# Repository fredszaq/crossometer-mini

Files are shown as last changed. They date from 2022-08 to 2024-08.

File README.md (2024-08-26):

# crossometer-mini

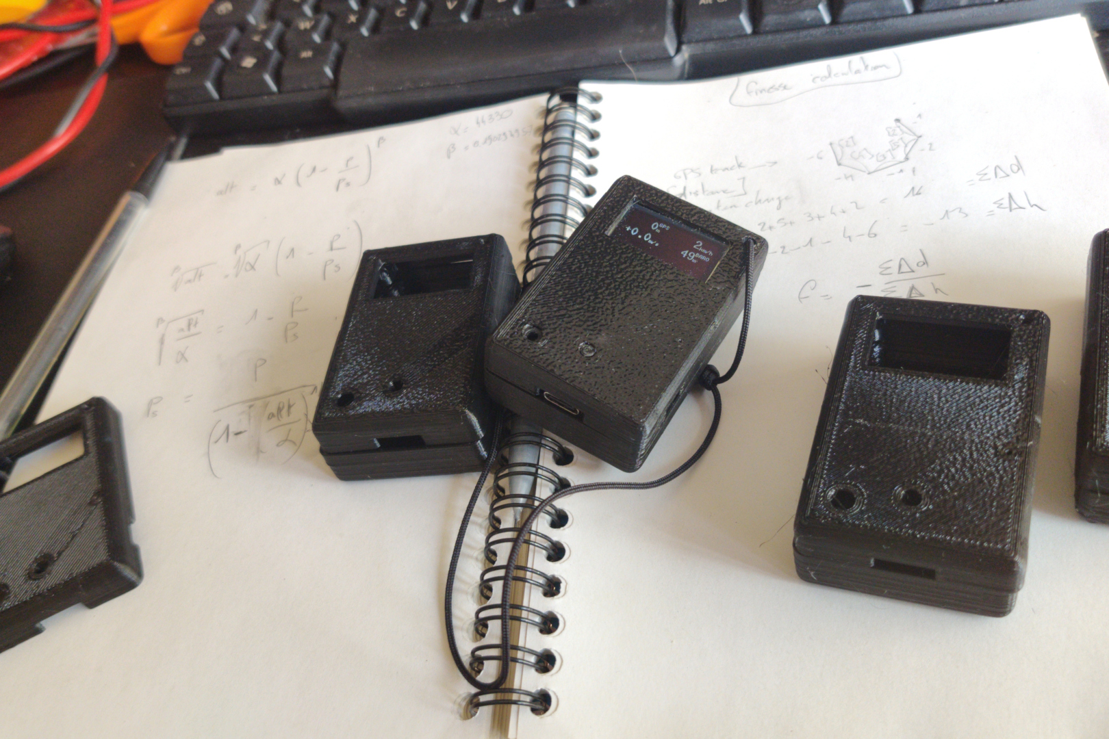
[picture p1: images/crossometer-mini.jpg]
crossometer-mini


This repo contains the design files for the crossometer-mini device, an open hardware GPS/altimeter/variometer using the [crossometer-firmware](https://github.com/fredszaq/crossometer-firmware).

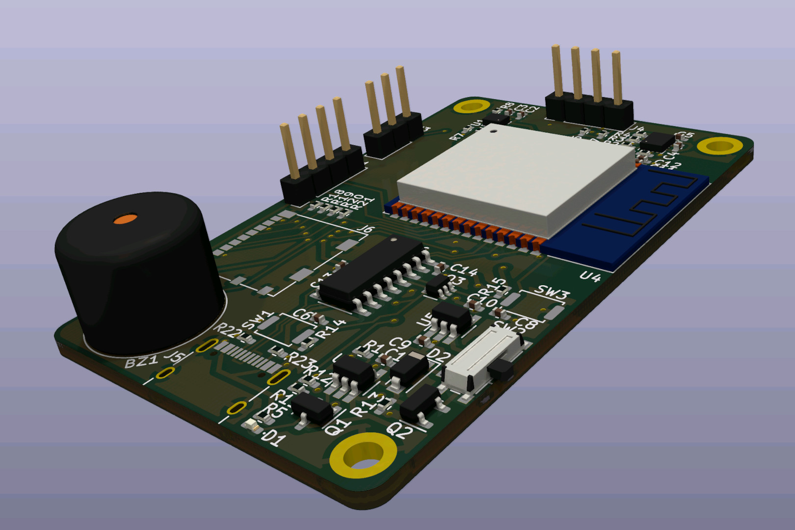
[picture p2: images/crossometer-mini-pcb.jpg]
crossometer-mini pcb


Provided are the Kicad files for the PCB and the Freecad files for the enclosure and clip.

Taking a look at open [issues](https://github.com/fredszaq/crossometer-mini/issues) may be a good idea if you intent do build a crossometer-mini for yourself.

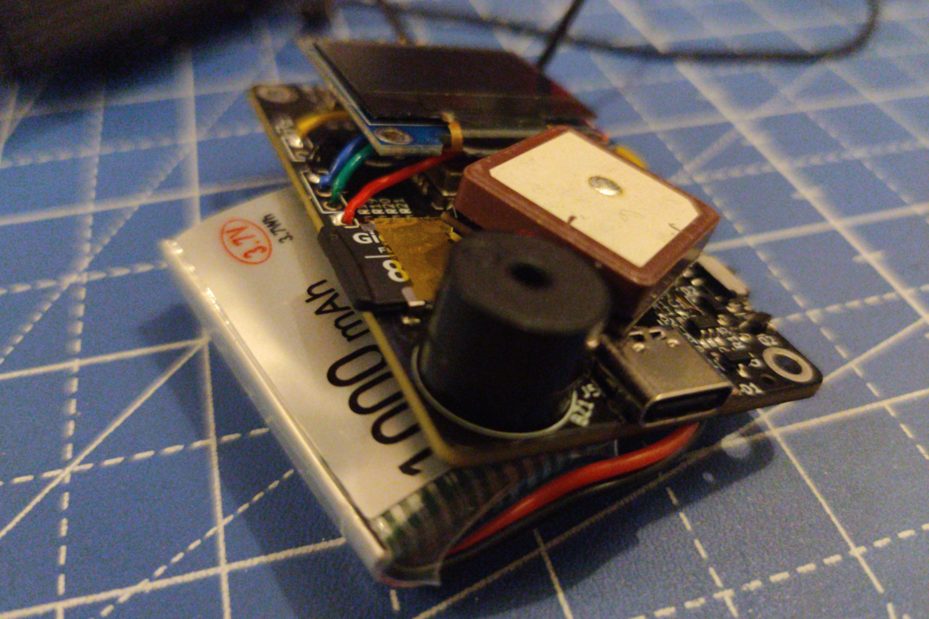
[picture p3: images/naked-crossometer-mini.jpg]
crossometer-mini without 3 case


Have a look at the [releases](https://github.com/fredszaq/crossometer-mini/releases) page to get gerber files and STLs.

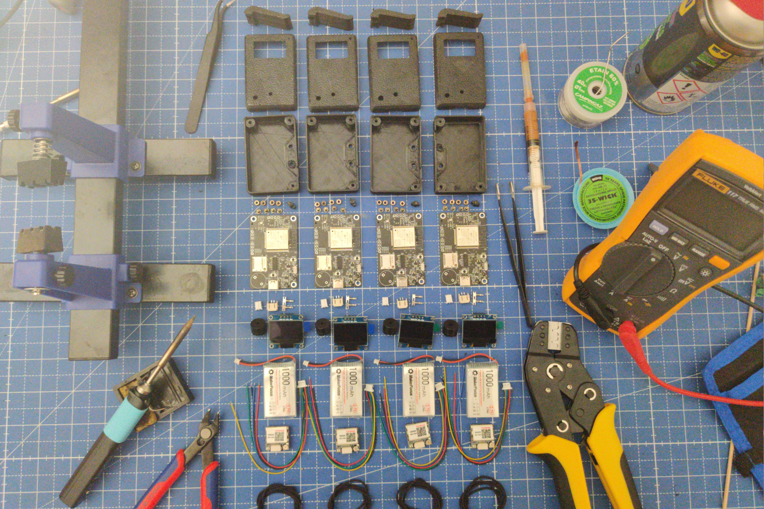
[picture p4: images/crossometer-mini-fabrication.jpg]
4 crossometer-mini before assembly


crossometer-mini is licenced under the CERN Open Hardware Licence Version 2 - Strongly Reciprocal

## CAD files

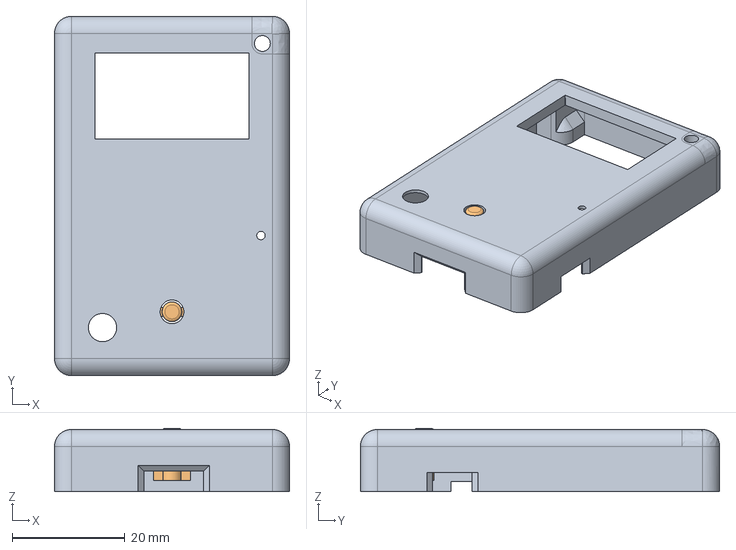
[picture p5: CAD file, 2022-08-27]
crossometer-mini.FCStd
41.6 x 63.6 x 11.2 mm
top
button

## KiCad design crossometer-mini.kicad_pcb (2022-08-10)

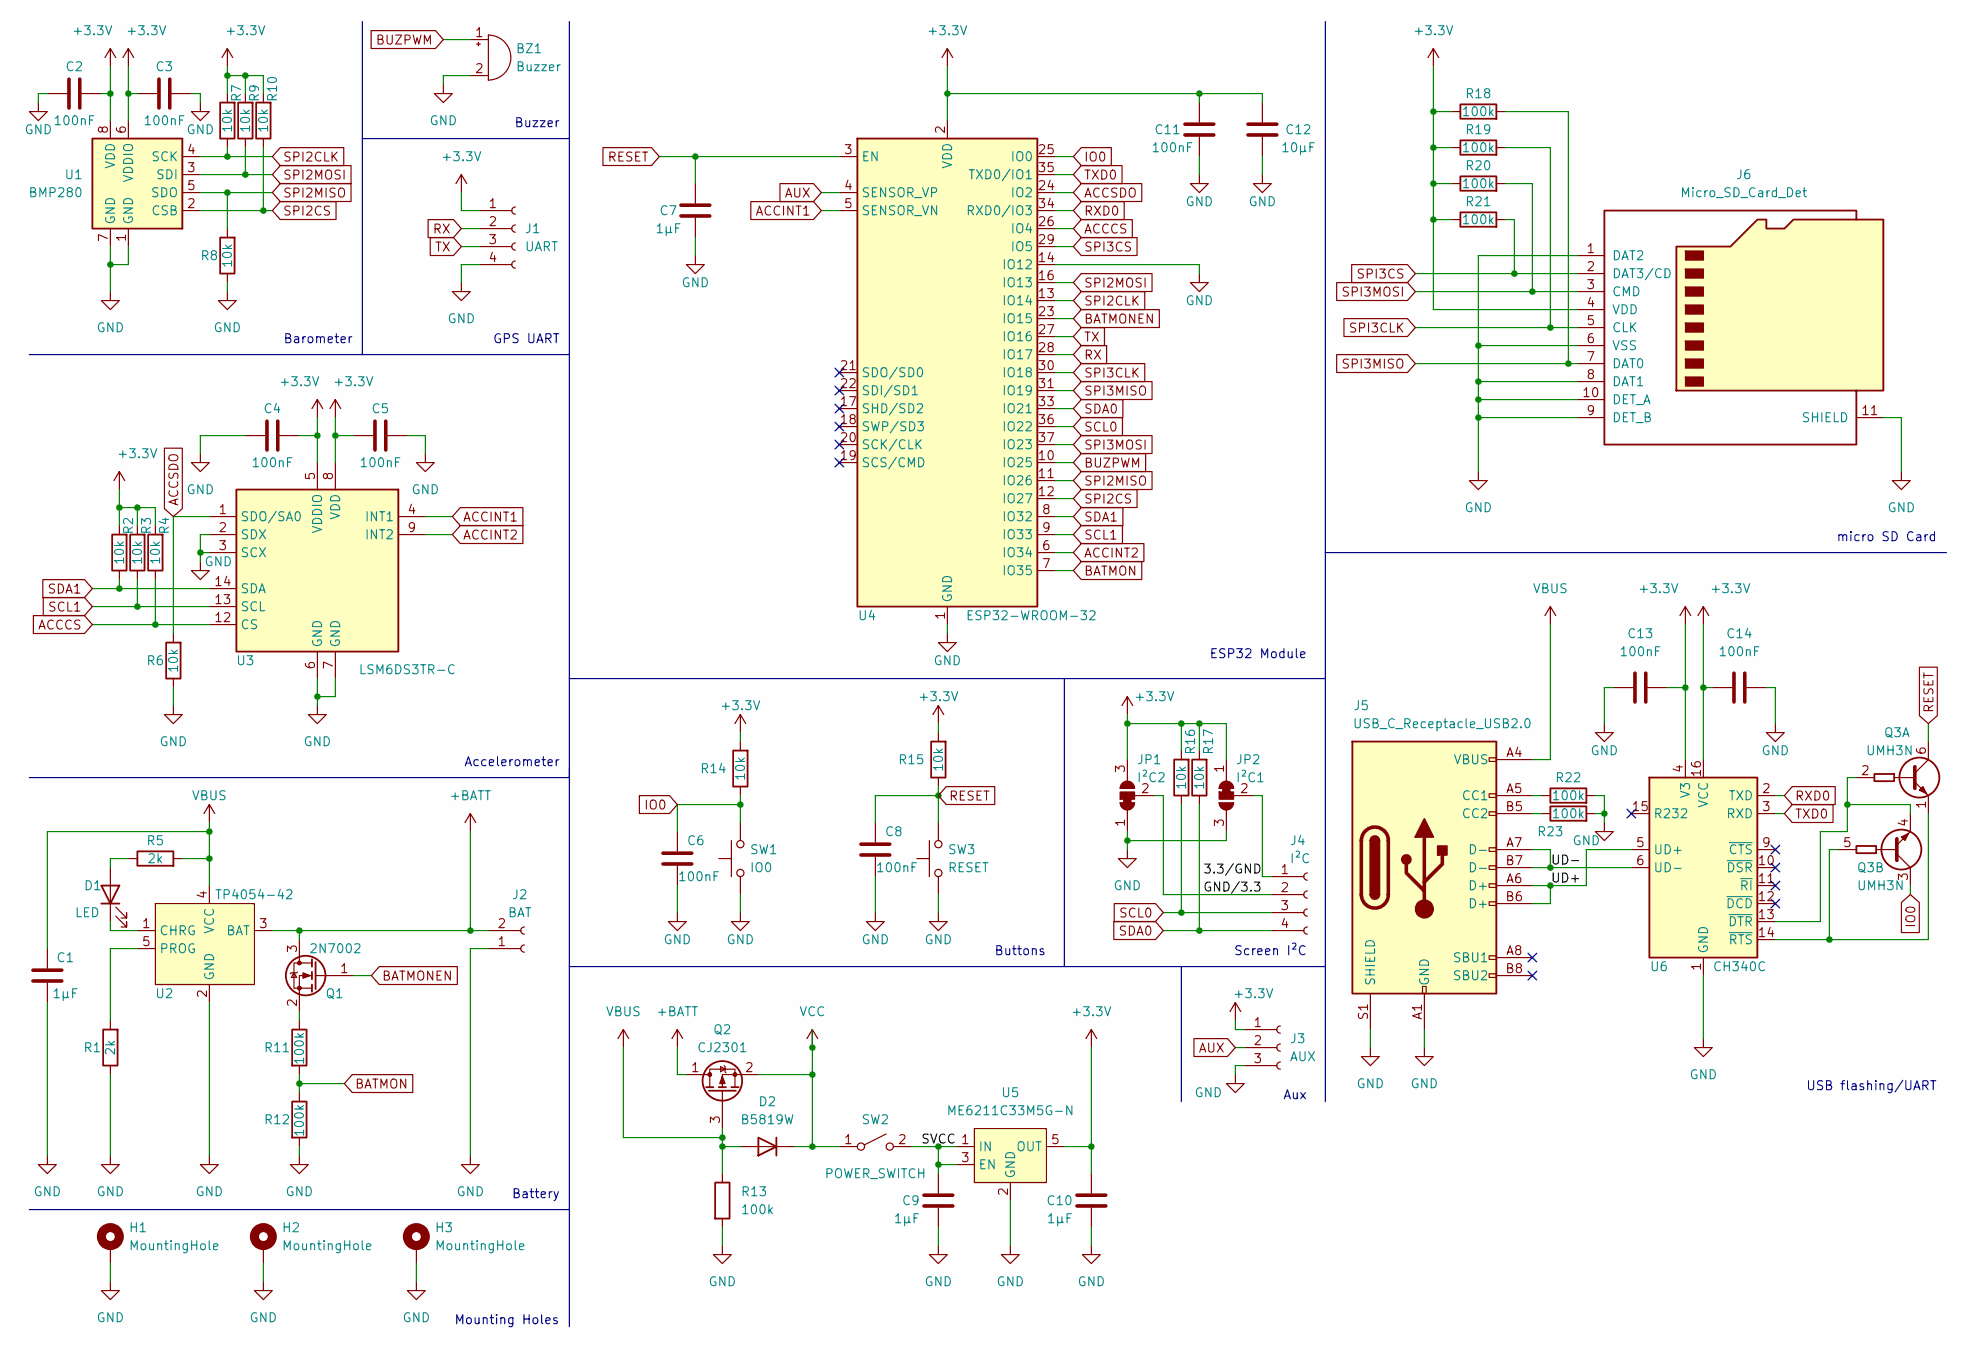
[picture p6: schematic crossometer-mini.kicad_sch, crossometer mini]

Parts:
BZ1: Buzzer; Buzzer_12x9.5RM7.6
C1, C7, C9, C10: 1µF; C_0402_1005Metric_Pad0.74x0.62mm_HandSolder; LCSC C52923
C2, C3, C4, C5, C6, C8, C11, C13, C14: 100nF; C_0402_1005Metric_Pad0.74x0.62mm_HandSolder; LCSC C1525
C12: 10µF; C_0402_1005Metric_Pad0.74x0.62mm_HandSolder; LCSC C15525
D1: LED; LED_0402_1005Metric_Pad0.77x0.64mm_HandSolder; LCSC C965790
D2: B5819W; D_SOD-123; LCSC C8598
H1, H2, H3: MountingHole; MountingHole_2.7mm_M2.5_ISO7380_Pad
J1: UART; PinHeader_1x04_P2.54mm_Vertical
J2: BAT; JST_PH_S2B-PH-SM4-TB_1x02-1MP_P2.00mm_Horizontal
J3: AUX; PinHeader_1x03_P2.54mm_Vertical
J4: I²C; PinHeader_1x04_P2.54mm_Vertical
J5: USB_C_Receptacle_USB2.0; USB_C_Receptacle_XKB_U262-16XN-4BVC11; LCSC C319148
J6: Micro_SD_Card_Det; microSD_HC_Molex_104031-0811; LCSC C585350
JP1: I²C2; SolderJumper-3_P1.3mm_Bridged12_RoundedPad1.0x1.5mm_NumberL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
JP2: I²C1; SolderJumper-3_P1.3mm_Bridged12_RoundedPad1.0x1.5mm_NumberL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
Q1: 2N7002; SOT-23; LCSC C8545
Q2: CJ2301; SOT-23; LCSC C2910170
Q3: UMH3N; SOT-363_SC-70-6; LCSC C62892
R1, R5: 2k; R_0402_1005Metric_Pad0.72x0.64mm_HandSolder; LCSC C4109
R2, R3, R4, R6, R7, R8, R9, R10, R14, R15, R16, R17: 10k; R_0402_1005Metric_Pad0.72x0.64mm_HandSolder; LCSC C25744
R11, R12, R13, R18, R19, R20, R21, R22, R23: 100k; R_0402_1005Metric_Pad0.72x0.64mm_HandSolder; LCSC C25741
SW1: IO0; SW_Push_SPST_NO_Alps_SKRK; LCSC C115357
SW2: POWER_SWITCH; SW_SPDT_PCM12; LCSC C221841
SW3: RESET; SW_Push_SPST_NO_Alps_SKRK; LCSC C115357
U1: BMP280; Bosch_LGA-8_2x2.5mm_P0.65mm_ClockwisePinNumbering; LCSC C83291
U2: TP4054-42; SOT-23-5_HandSoldering; LCSC C32574
U3: LSM6DS3TR-C; Bosch_LGA-14_3x2.5mm_P0.5mm; LCSC C967633
U4: ESP32-WROOM-32; LCSC C82899
U5: ME6211C33M5G-N; SOT-23-5_HandSoldering; LCSC C82942
U6: CH340C; SOIC-16_3.9x9.9mm_P1.27mm; LCSC C84681

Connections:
+3V3: C2.1, C3.2, C4.1, C5.2, C10.1, C11.1, C12.1, C13.2, C14.1, J1.1, J3.1, J6.4 (VDD), JP1.3 (B), JP2.1 (A), R2.2, R3.2, R4.2, R7.2, R9.2, R10.2, R14.2, R15.2, R16.2, R17.2, R18.1, R19.1, R20.1, R21.1, U1.6 (VDDIO), U1.8 (VDD), U3.5 (VDDIO), U3.8 (VDD), U4.2 (VDD), U5.5 (OUT), U6.4 (V3), U6.16 (VCC)
+BATT: J2.2, Q1.3 (D), Q2.1 (D), U2.3 (BAT)
/3.3/GND: J4.1, JP2.2 (C)
/GND/3.3: J4.2, JP1.2 (C)
/SVCC: C9.1, SW2.2 (B), U5.1 (IN), U5.3 (EN)
/UD+: J5.A6 (D+), J5.B6 (D+), U6.5 (UD+)
/UD-: J5.A7 (D-), J5.B7 (D-), U6.6 (UD-)
ACCCS: R4.1, U3.12 (CS), U4.26 (IO4)
ACCINT1: U3.4 (INT1), U4.5 (SENSOR_VN)
ACCINT2: U3.9 (INT2), U4.6 (IO34)
ACCSDO: R6.2, U3.1 (SDO/SA0), U4.24 (IO2)
AUX: J3.2, U4.4 (SENSOR_VP)
BATMON: R11.2, R12.1, U4.7 (IO35)
BATMONEN: Q1.1 (G), U4.23 (IO15)
BUZPWM: BZ1.1 (-), U4.10 (IO25)
GND: BZ1.2 (+), C1.1, C2.2, C3.1, C4.2, C5.1, C6.2, C7.2, C8.2, C9.2, C10.2, C11.2, C12.2, C13.1, C14.2, H1.1, H2.1, H3.1, J1.4, J2.1, J3.3, J5.A1 (GND), J5.A12 (GND), J5.B1 (GND), J5.B12 (GND), J5.S1 (SHIELD), J6.1 (DAT2), J6.6 (VSS), J6.8 (DAT1), J6.9 (DET_B), J6.10 (DET_A), J6.11 (SHIELD), JP1.1 (A), JP2.3 (B), R1.1, R6.1, R8.1, R12.2, R13.2, R22.2, R23.2, SW1.1, SW3.1, U1.1 (GND), U1.7 (GND), U2.2 (GND), U3.2 (SDX), U3.3 (SCX), U3.6 (GND), U3.7 (GND), U4.1 (GND), U4.14 (IO12), U4.15 (GND), U4.38 (GND), U4.39 (GND), U5.2 (GND), U6.1 (GND)
IO0: C6.1, Q3.3 (C2), R14.1, SW1.2, U4.25 (IO0)
unnamed: D1.1 (K), U2.1 (CHRG)
unnamed: D1.2 (A), R5.1
unnamed: J5.A5 (CC1), R22.1
unnamed: J5.B5 (CC2), R23.1
unnamed: Q1.2 (S), R11.1
unnamed: Q3.1 (E1), Q3.5 (B2), U6.14 (~RTS)
unnamed: Q3.2 (B1), Q3.4 (E2), U6.13 (~DTR)
unnamed: R1.2, U2.5 (PROG)
RESET: C7.1, C8.1, Q3.6 (C1), R15.1, SW3.2, U4.3 (EN)
RX: J1.2, U4.28 (IO17)
RXD0: U4.34 (RXD0/IO3), U6.2 (TXD)
SCL0: J4.3, R16.1, U4.36 (IO22)
SCL1: R3.1, U3.13 (SCL), U4.9 (IO33)
SDA0: J4.4, R17.1, U4.33 (IO21)
SDA1: R2.1, U3.14 (SDA), U4.8 (IO32)
SPI2CLK: R7.1, U1.4 (SCK), U4.13 (IO14)
SPI2CS: R10.1, U1.2 (CSB), U4.12 (IO27)
SPI2MISO: R8.2, U1.5 (SDO), U4.11 (IO26)
SPI2MOSI: R9.1, U1.3 (SDI), U4.16 (IO13)
SPI3CLK: J6.5 (CLK), R19.2, U4.30 (IO18)
SPI3CS: J6.2 (DAT3/CD), R21.2, U4.29 (IO5)
SPI3MISO: J6.7 (DAT0), R18.2, U4.31 (IO19)
SPI3MOSI: J6.3 (CMD), R20.2, U4.37 (IO23)
TX: J1.3, U4.27 (IO16)
TXD0: U4.35 (TXD0/IO1), U6.3 (RXD)
VBUS: C1.2, D2.2 (A), J5.A4 (VBUS), J5.A9 (VBUS), J5.B4 (VBUS), J5.B9 (VBUS), Q2.3 (G), R5.2, R13.1, U2.4 (VCC)
VCC: D2.1 (K), Q2.2 (S), SW2.1 (A)

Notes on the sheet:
USB flashing/UART
micro SD Card
ESP32 Module
Accelerometer
Buttons
Buzzer
Mounting Holes
Battery
Screen I²C
GPS UART
Aux
Barometer

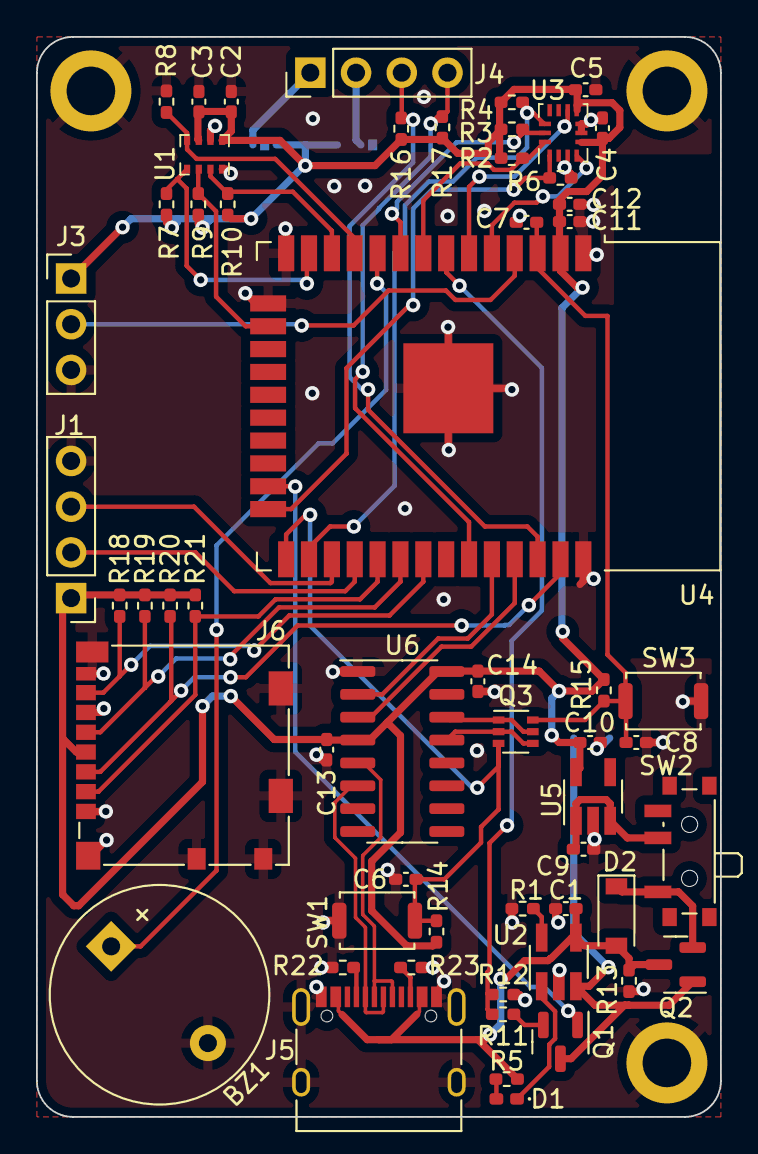
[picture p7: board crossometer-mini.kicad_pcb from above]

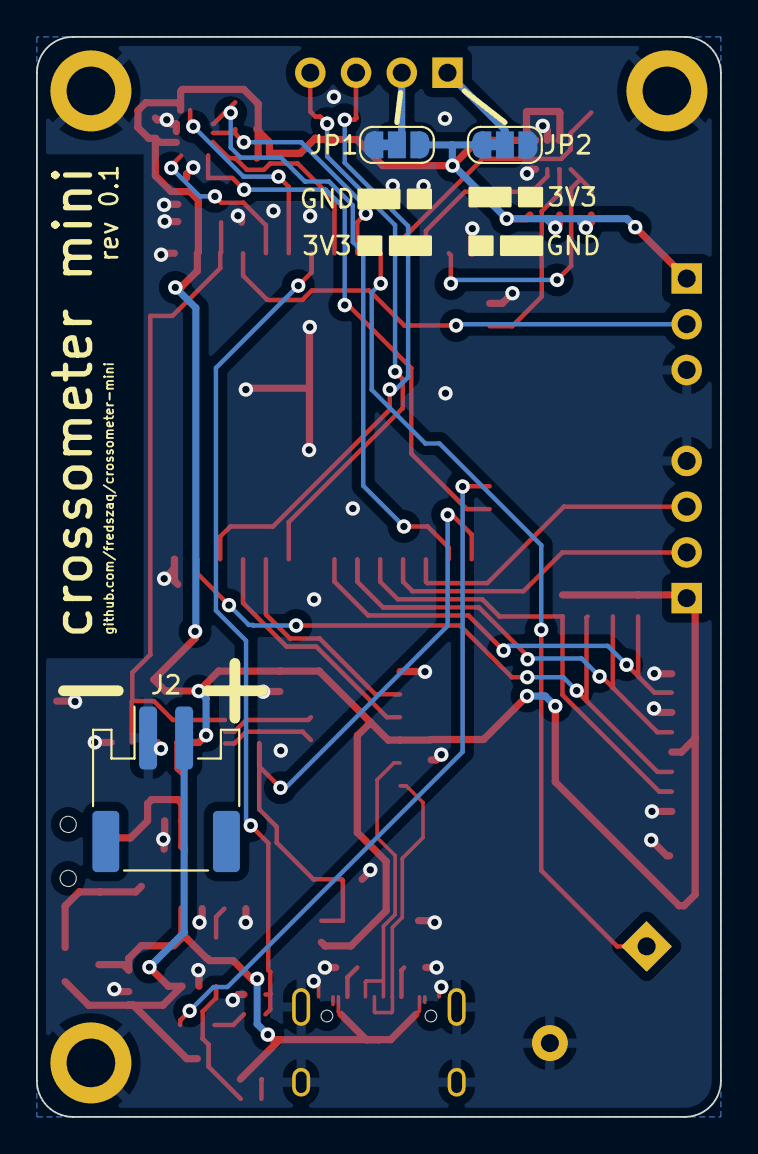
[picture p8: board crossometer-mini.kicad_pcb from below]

Board: 2 copper layers, 38.0 x 60.0 mm, 63 parts (3 on the bottom side), 44 nets.

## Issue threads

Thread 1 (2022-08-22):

Gate and drain pins inverted on mosfet Q2

fredszaq, 2022-08-22:
order in schematic is
1 -> drain
2 -> source
3 -> gate
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

whereas in CJ2301 datasheet order is
1 -> drain
2 -> source
3 -> gate

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

fredszaq, 2022-08-22:
# FIX on 0.1 boards

 - unsolder Q2
 - bend the pins the other way
 - solder it back upside down at a ~60° angle, the top pin stays in its place, the left and bottom pins are switched

original board :
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

fixed board :
 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

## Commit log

2022-08-10 add LCSC field to schematic
    [crossometer-mini.kicad_pcb, crossometer-mini.kicad_sch]
2022-08-27 add 3d design files
    [crossometer-mini.FCStd]
2024-08-26 kicad 8 changes
    [crossometer-mini.kicad_sch]
2024-08-26 add pcb 3d render to readme
